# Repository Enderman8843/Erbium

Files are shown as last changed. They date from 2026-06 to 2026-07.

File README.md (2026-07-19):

# Erbium

It is Hi-Speed USB HUB with USB2514B_B Chip and 24mhz crystal , With Support of USB C aswell as USB A

## How To Use ?
JUST PlUG IT INTO YOUR COMPUTER VIA THE INPUT

## Why did I built it 
I built this project because I wanted learn more about usb hubs and their working , WHile this hub also helps me to work with my RPI 2 zero , which dosent have many usb ports and hence allowing me to connect multiple peripeheral devices to it 

# PCB Layout

| PCB Layout | Schematic / Wiring |
|---|---|
| PCB Layout | Schematic / Wiring |

# PCB Render

| Front | Rear |
|---|---|
| PCB Front Render | PCB Rear Render |

# Case 



---

# BOM

| Item | Description | Quantity | Unit Price ($) | Total Price ($) | URL |
|---|---|---|---|---|-----|
| PCBA | Custom PCB Manufacturing (JLCPCB) | 1 | 31.00 | 31.00 | https://jlcpcb.com |
| Case | 3D Printed Case (Will be Printed Myself | 1 | 0.00 | 0.00 | https://hackclub.com |
| USB Connector | USB Type-A Vertical Through-Hole Connector (Adam Tech USB-A-S-VT) | 1 | 2.00 | 2.00 | https://www.digikey.in/en/products/detail/adam-tech/USB-A-S-VT/9832290 |
| **TOTAL** |  |  |  | **33.00** |  |

# JLCPCB and Shipping



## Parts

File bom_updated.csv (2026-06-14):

Item | Description | Quantity | Unit Price ($) | Total Price ($) | URL
PCBA | Custom PCB Manufacturing (JLCPCB) | 1 | 31.0 | 31.0 | https://jlcpcb.com
Case | 3D Printed Case (Will be Printed Myself) | 1 | 0.0 | 0.0 | https://hackclub.com
USB Connector | USB Type-A Vertical Through-Hole Connector (Adam Tech USB-A-S-VT) | 1 | 2.0 | 2.0 | https://www.digikey.in/en/products/detail/adam-tech/USB-A-S-VT/9832290
TOTAL |  |  |  | 33.0

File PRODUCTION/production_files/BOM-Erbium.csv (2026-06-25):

Comment | Designator | Footprint | LCSC | Quantity
56k | R2 | C_0603_1608Metric |  | 1
5.1k | R7 | C_0603_1608Metric |  | 1
0.1µF | C12 | C_0603_1608Metric |  | 1
56k | R1 | C_0603_1608Metric |  | 1
0.1µF | C9 | C_0603_1608Metric |  | 1
56k | R4 | C_0603_1608Metric |  | 1
0.1µF | C11 | C_0603_1608Metric |  | 1
12k | R6 | C_0603_1608Metric |  | 1
USB_A | J1 | USB_A_Molex_105057_Vertical |  | 1
USB_C_Receptacle_USB2.0_16P | J4 | USB_C_Receptacle_G-Switch_GT-USB-7010ASV |  | 1
USB_C_Receptacle_USB2.0_16P | J3 | USB_C_Receptacle_G-Switch_GT-USB-7010ASV |  | 1
5.1k | R8 | C_0603_1608Metric |  | 1
USB_C_Receptacle_USB2.0_16P | J5 | USB_C_Receptacle_G-Switch_GT-USB-7010ASV |  | 1
22pf | C8 | C_0603_1608Metric |  | 1
Crystal | 24Mhz1 | Crystal_SMD_3225-4Pin_3.2x2.5mm |  | 1
USB_A | J2 | USB_A_Molex_105057_Vertical |  | 1
10k | R5 | C_0603_1608Metric |  | 1
0.1µF | C5 | C_0603_1608Metric |  | 1
22pf | C7 | C_0603_1608Metric |  | 1
56k | R3 | C_0603_1608Metric |  | 1
USB2514B_Bi | U1 | QFN-36-1EP_6x6mm_P0.5mm_EP3.7x3.7mm |  | 1
0.1µF | C10 | C_0603_1608Metric |  | 1

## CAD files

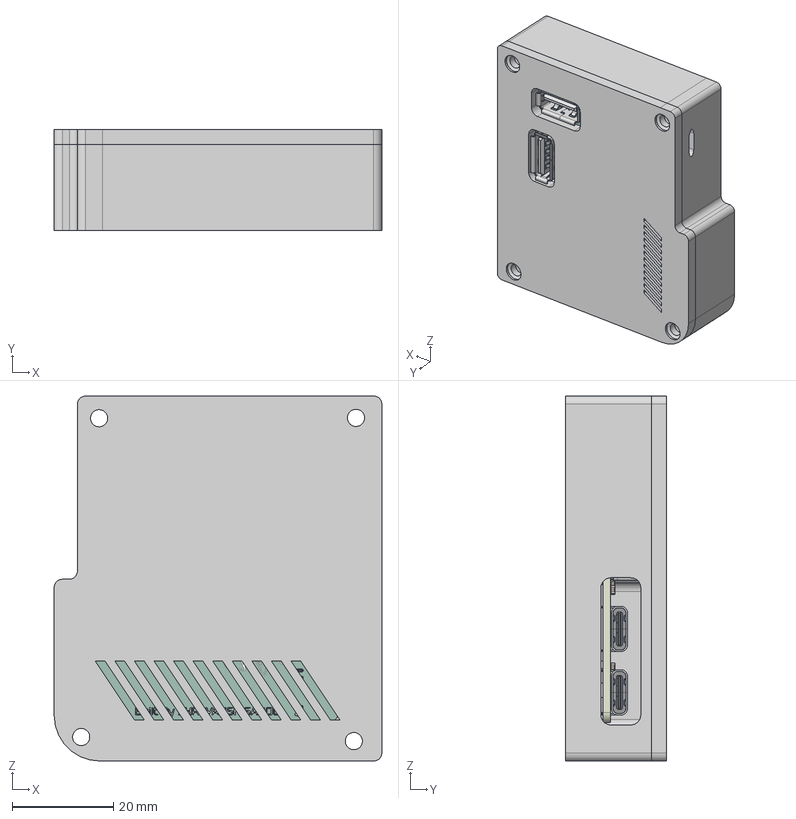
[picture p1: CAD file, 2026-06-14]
CAD/Erbium.step
64.7 x 20.0 x 72.1 mm

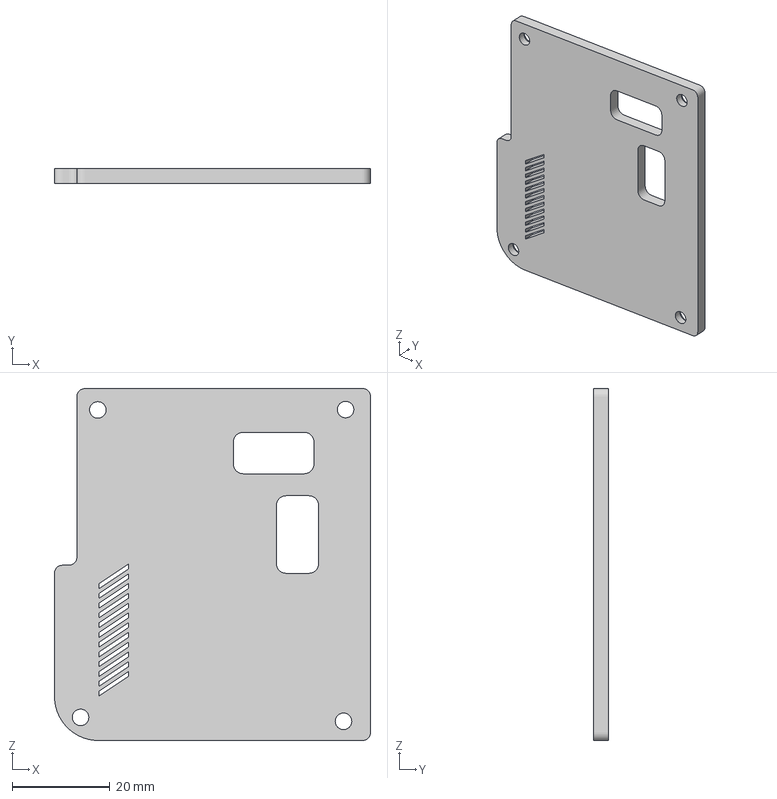
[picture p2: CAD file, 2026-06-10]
CAD/SeparatedBodies/ErbUper.3mf
64.7 x 3.00 x 72.1 mm

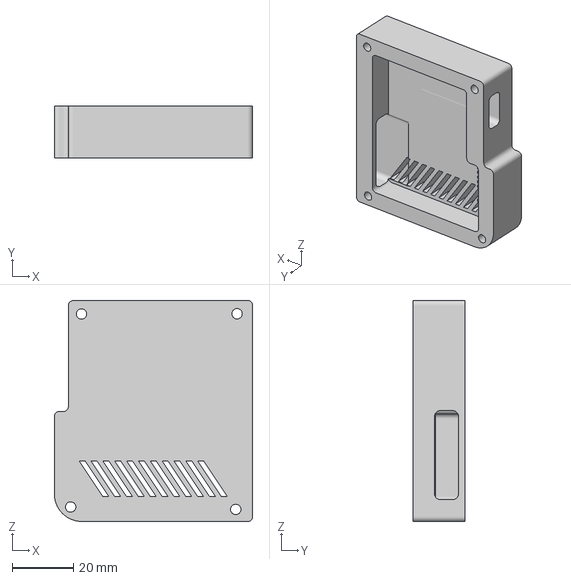
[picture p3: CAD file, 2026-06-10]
CAD/SeparatedBodies/ErbiumLower.3mf
64.7 x 17.0 x 72.1 mm

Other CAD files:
CAD/Erbium.3mf
CAD/Erbium.f3z

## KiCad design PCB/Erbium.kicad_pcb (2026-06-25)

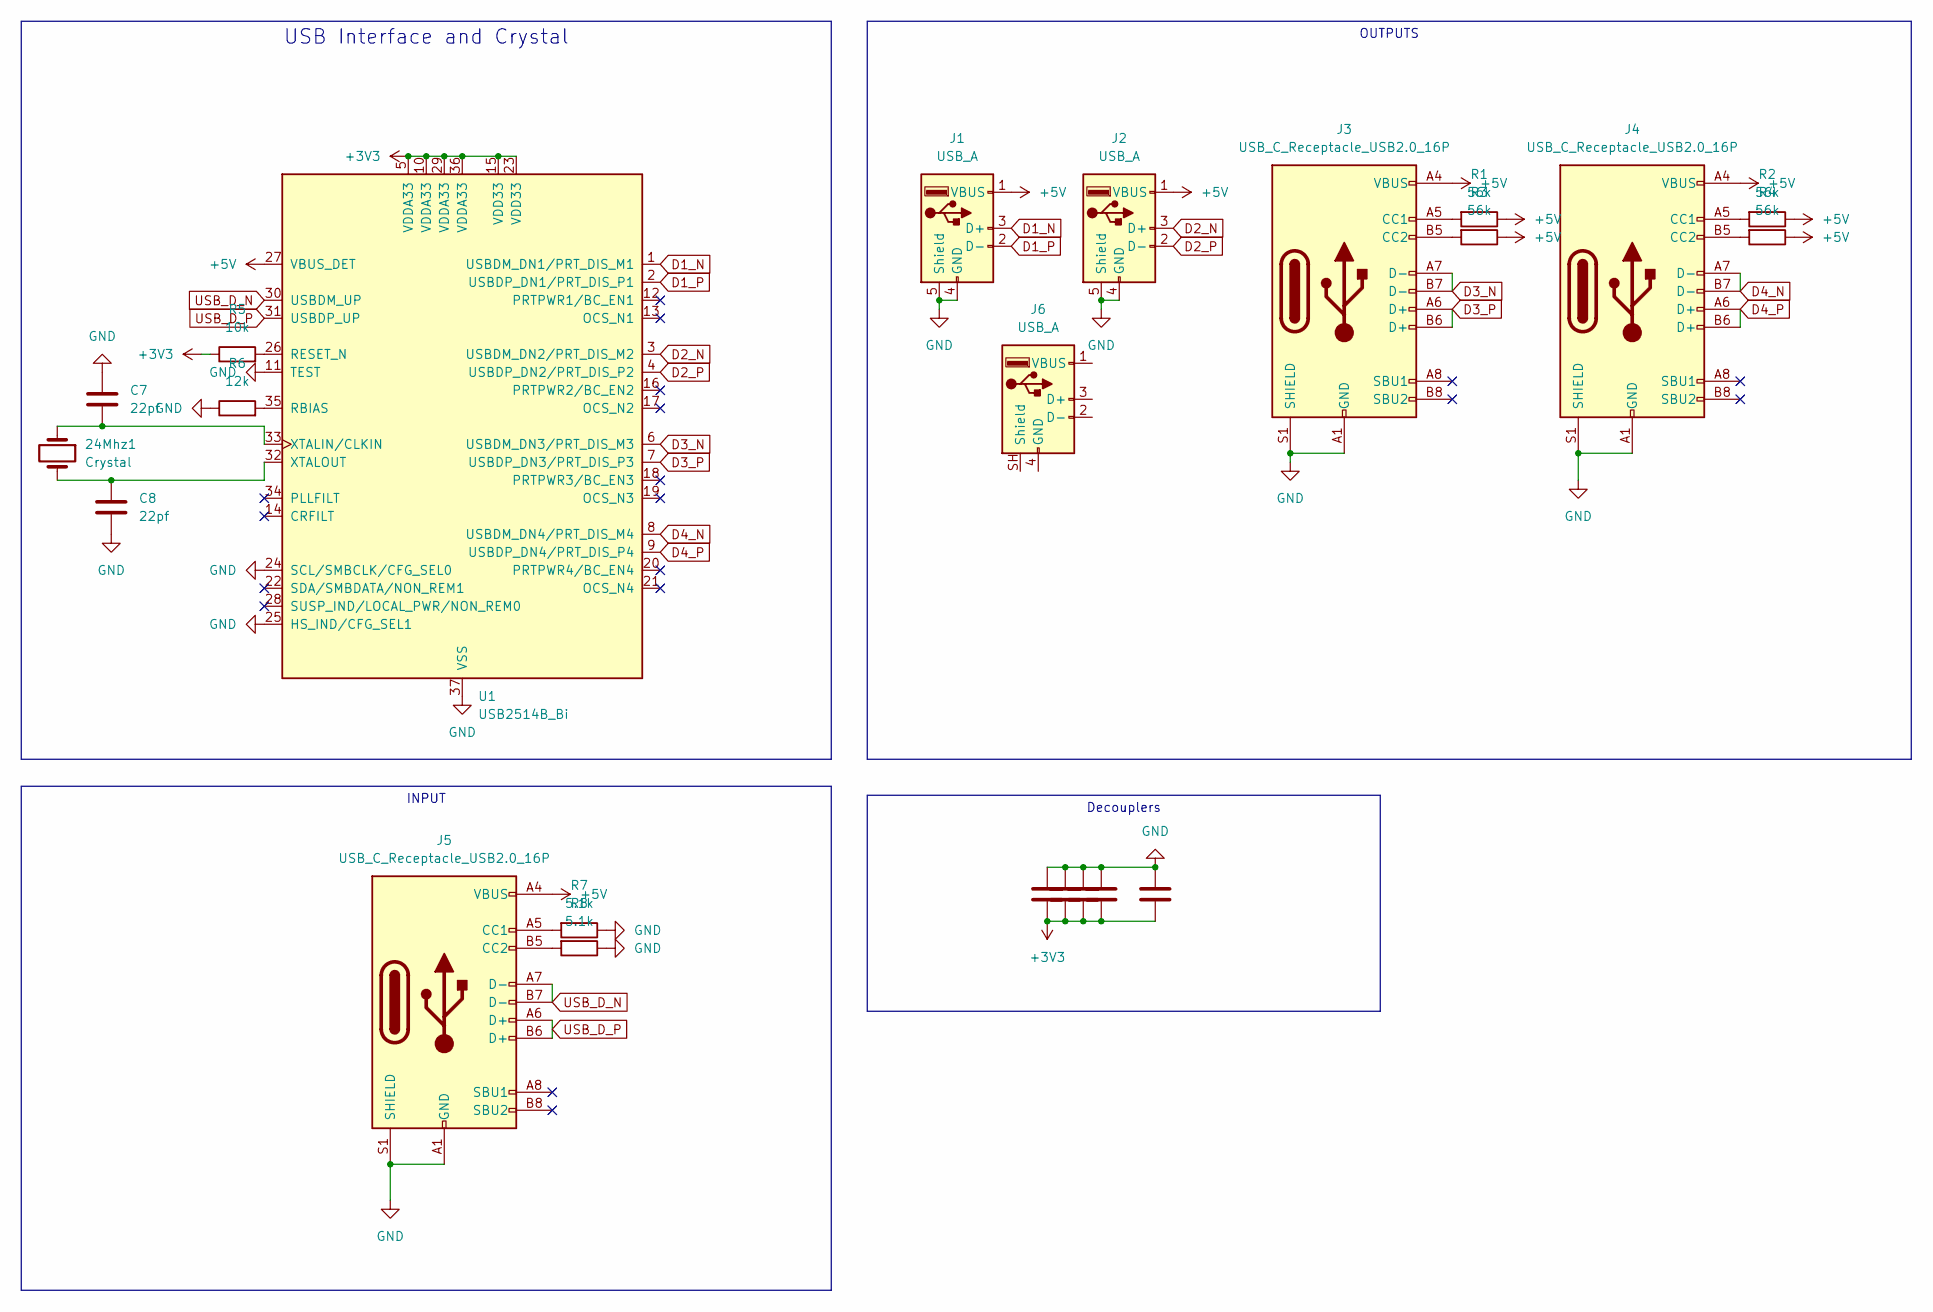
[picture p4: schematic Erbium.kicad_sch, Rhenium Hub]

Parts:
24Mhz1: Crystal; Crystal_SMD_3225-4Pin_3.2x2.5mm
C5, C9, C10, C11, C12: 0.1µF; C_0603_1608Metric
C7, C8: 22pf; C_0603_1608Metric
J1, J2: USB_A; USB_A_Molex_105057_Vertical
J3, J4, J5: USB_C_Receptacle_USB2.0_16P; USB_C_Receptacle_G-Switch_GT-USB-7010ASV
J6: USB_A
R1, R2, R3, R4: 56k; C_0603_1608Metric
R5: 10k; C_0603_1608Metric
R6: 12k; C_0603_1608Metric
R7, R8: 5.1k; C_0603_1608Metric
U1: USB2514B_Bi; QFN-36-1EP_6x6mm_P0.5mm_EP3.7x3.7mm

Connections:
+3V3: C5.2, C9.2, C10.2, C11.2, C12.2, R5.1, U1.5 (VDDA33), U1.10 (VDDA33), U1.15 (VDD33), U1.23 (VDD33), U1.29 (VDDA33), U1.36 (VDDA33)
+5V: J1.1 (VBUS), J2.1 (VBUS), J3.A4 (VBUS), J3.A9 (VBUS), J3.B4 (VBUS), J3.B9 (VBUS), J4.A4 (VBUS), J4.A9 (VBUS), J4.B4 (VBUS), J4.B9 (VBUS), J5.A4 (VBUS), J5.A9 (VBUS), J5.B4 (VBUS), J5.B9 (VBUS), R1.1, R2.1, R3.1, R4.1, U1.27 (VBUS_DET)
D1_N: J1.3 (D+), U1.1 (USBDM_DN1/PRT_DIS_M1)
D1_P: J1.2 (D-), U1.2 (USBDP_DN1/PRT_DIS_P1)
D2_N: J2.3 (D+), U1.3 (USBDM_DN2/PRT_DIS_M2)
D2_P: J2.2 (D-), U1.4 (USBDP_DN2/PRT_DIS_P2)
D3_N: J3.A7 (D-), J3.B7 (D-), U1.6 (USBDM_DN3/PRT_DIS_M3)
D3_P: J3.A6 (D+), J3.B6 (D+), U1.7 (USBDP_DN3/PRT_DIS_P3)
D4_N: J4.A7 (D-), J4.B7 (D-), U1.8 (USBDM_DN4/PRT_DIS_M4)
D4_P: J4.A6 (D+), J4.B6 (D+), U1.9 (USBDP_DN4/PRT_DIS_P4)
GND: C5.1, C7.1, C8.2, C9.1, C10.1, C11.1, C12.1, J1.4 (GND), J1.5 (Shield), J2.4 (GND), J2.5 (Shield), J3.A1 (GND), J3.A12 (GND), J3.B1 (GND), J3.B12 (GND), J3.S1 (SHIELD), J4.A1 (GND), J4.A12 (GND), J4.B1 (GND), J4.B12 (GND), J4.S1 (SHIELD), J5.A1 (GND), J5.A12 (GND), J5.B1 (GND), J5.B12 (GND), J5.S1 (SHIELD), R6.1, R7.1, R8.1, U1.11 (TEST), U1.24 (SCL/SMBCLK/CFG_SEL0), U1.25 (HS_IND/CFG_SEL1), U1.37 (VSS)
unnamed: J3.A5 (CC1), R1.2
unnamed: J3.B5 (CC2), R3.2
unnamed: J4.A5 (CC1), R2.2
unnamed: J4.B5 (CC2), R4.2
unnamed: J5.A5 (CC1), R7.2
unnamed: J5.B5 (CC2), R8.2
unnamed: R6.2, U1.35 (RBIAS)
unnamed: R5.2, U1.26 (RESET_N)
unnamed: 24Mhz1.1, C7.2, U1.33 (XTALIN/CLKIN)
unnamed: 24Mhz1.2, C8.1, U1.32 (XTALOUT)
USB_D_N: J5.A7 (D-), J5.B7 (D-), U1.30 (USBDM_UP)
USB_D_P: J5.A6 (D+), J5.B6 (D+), U1.31 (USBDP_UP)

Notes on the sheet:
INPUT
OUTPUTS
Decouplers
USB Interface and Crystal

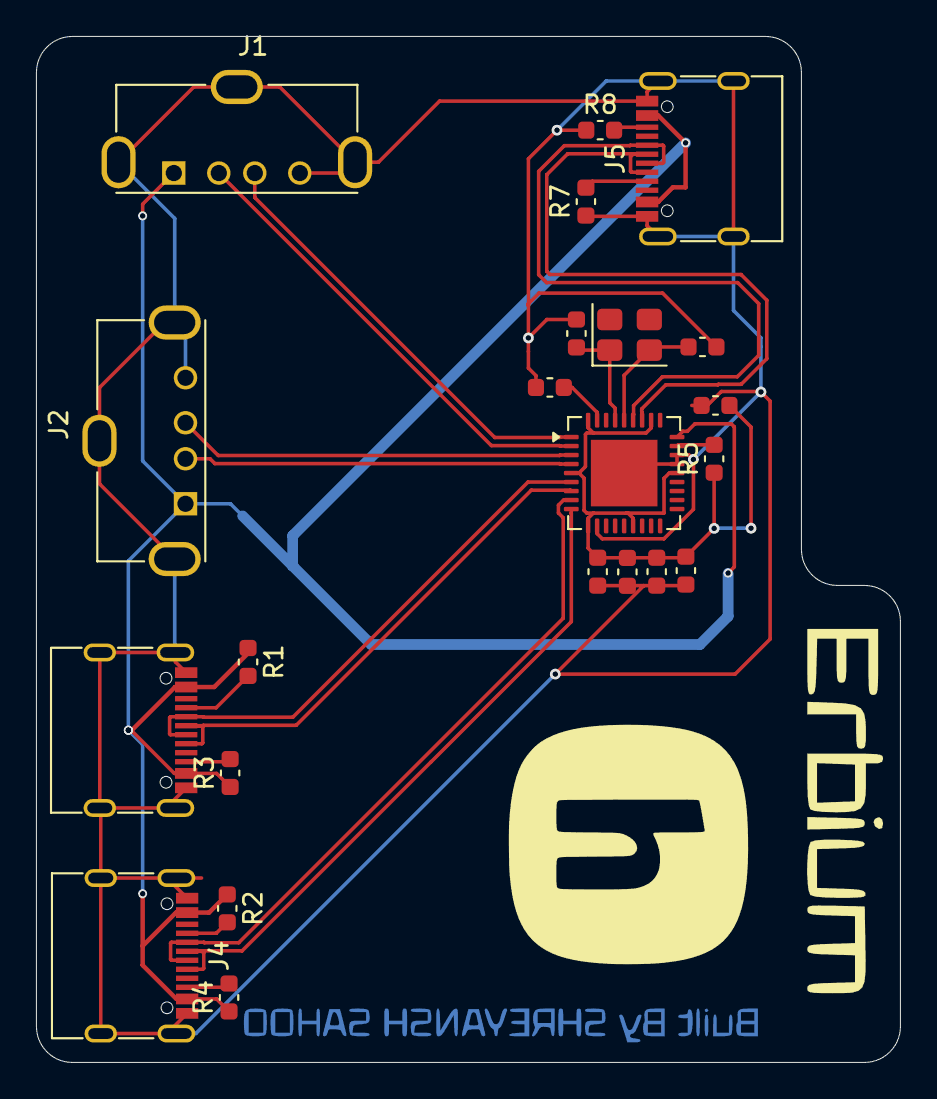
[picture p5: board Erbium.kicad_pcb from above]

Board: 2 copper layers, 48.0 x 57.0 mm, 22 parts (0 on the bottom side), 23 nets.

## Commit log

2026-05-17 Updated the pcb
    [Rhenium-Hub.kicad_pcb, Rhenium-Hub.kicad_sch]
2026-06-14 Modify case description and recalculate total price
    Updated the case description and adjusted total price.
